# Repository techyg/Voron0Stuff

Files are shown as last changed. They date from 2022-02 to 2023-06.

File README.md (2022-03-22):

# Voron0Stuff

Welome to my Voron Stuff Repository! This is where I dump files to help share what I am working on with the Voron community. You probably found this link via my Youtube Channel (Greg's Maker Corner) or through Discord.

Check out my channel by going here:
http://www.gregsmakercorner.com

Klipper Configuration Files:

** Note: Klipper often has new releases with breaking changes. I try to keep these files updated, but please beware that they may not work with the latest version of Klipper. This is especially true of the printer.cfg files which seem to break more frequently. 

DisplayEncoder.cfg - for use with the Voron 0 display. Make sure you include this file from your printer.cfg using [include DisplayEncoder.cfg]

DisplayMenu.cfg - this specifies all the custom menu options. Make sure you include this file from your printer.cfg using [include DisplayMenu.cfg]

klipper_Expander.cfg - the config file that I use for my klipper expander. Must be included from printer.cfg file.

ldokit-voron01.cfg - my printer.cfg file for the LDO Kit v0.1.

voron01-0.5-printer.cfg - printer.cfg file for my original v0.1, which uses an AC Bed and the original v0.0 motors.

Slicer Files - Prusa Slicer

Prusa*.* - Slicer profiles I use for ASA, TPU, ABS

Slicer Files - Idea Maker

Voron 0.1-export.printer  - my voron 0 printer configuration file

V0 ABS-export.bin - My ABS Settings.

V0 PLA-export.bin - My Slicer settings.

V0 TPU-export.bin - Generic TPU settings.

V0 TPE-Inland     - Settings for Inland TPE (Shore Hardness 87A)

V0 TPU-NinjaFlex  - Settings for Ninjaflex TPU (Shore Hardness 85A)

V0 TPU-SainSmart  - Settings for Sainsmart TPU (Shore Hardness 95A)

Please note that you may need to add some GCODE sections for the slicing profiles to work. Refer to my printer configuration file.

Other files:

LGXLiteHartKPCBMountv2.stl - Hartk PCB toolhead mount for the Stealthburner with LGX Lite. You will need to m3x8's (recommend using washers) and also two heat inserts for the PCB. 

LGXLiteHartKPCBMountv2.scad - Open SCAD source code file, you can customize the PCB mount fairly easily with this and Open SCAD.

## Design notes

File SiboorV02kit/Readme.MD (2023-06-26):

Kit Updates: June 2023-

Siboor now includes led nut bar adapters in their latest kits. Please double check that all screws operate before inserting (just to be on the safe side). Use my 3d printed nut adapters and m2 hex nuts if you prefer to use printed parts similar to stock. 

Learn more about the latest Changes Update to V02 kit: https://www.youtube.com/watch?v=YN2l0KVBhCg

Original Siboor V02 Kit Review:
https://www.youtube.com/watch?v=cOtdasw3uVo&t=0s

PLEASE READ BELOW FOR SIBOOR VORON 0.2 KIT NOTES. 

This repository is for all the Siboor v2 kit items that I am either changing/remixing, or noting. The goal of this is to help other Siboor V02 builders.

**Instructions for all parts: print with .1 layer for first layer to improve stiffness. The layer height is only .2 for the bottom, otherwise the nuts won't fit.
**

Modified Parts for Siboor Extrusions (MakerBeam XL). The V02 kit does include PCB inserts that you can use. If you'd rather use a plastic part, use the remix below. 

* Siboor-M2_Nut_Adapter_Rotated_x5 - remixed nut carriers that will fit the Siboor MakerBeam XL extrusions. (height reduced and width slightly reduced). 
Remixed from Voron 0.2 STL repository.
https://github.com/VoronDesign/Voron-0/tree/Voron0.2/STLs

Note: THE HEX NO NUT DROP IS A VERY TIGHT FIT AND MAY NOT WORK IN SOME CASES (see below for alternative Square Nut mod). 

The hex nuts included with the Siboor kit are approximately 2mm-2.3mm thick. The channel that the nuts can fit in is only 2.5mm tall as opposed to other extrusion designs (Mitsumi, LDO, Maker Beam XL which have more room). Unforunately, that leaves very little room for plastic No Drop nuts. 

This isn't a problem unless you want to use No Drop nuts, which make the build MUCH easier and less frustrating, especially for first time builders. Without using no drop nuts, you will have to constantly keep track of where your hexnuts are and most likely they will fall out frequently (particularly when doing the Z axis). If you want to have a good building experience, it is highly recommended to use the no drop nuts. Using no drop nuts also helps for the panels, otherwise you will have to reposition your printer every time you want to put the panels back on.

My remix below only has a .2mm thickness where the nut sits, which means they are really easy to break. I ran into issues and in some cases I had hex nuts that were too thick and these wouldn't work. 

* Siboor-V02_HexNut_1515.stl - intended to fit the included MakerBeam XL extrusions. 
Remixed from here: https://github.com/VoronDesign/VoronUsers/tree/master/printer_mods/Zen3D/V0_1515_T-nut/MakerBeam

As an alternative, you can purchase standard DIN 562 square nuts (1.8mm) and use my square no drop nut mod. This will fit much easier and be a lot less frustration putting together. 

Alternative square nuts (DIN 562):
https://amzn.to/3TCoJL9

* Siboor-V02_SqNut-1515.stl - No Drop nut holder for square nuts that are DIN 562 (1.8mm m3 hex nuts). 

Remixed from here: https://thangs.com/designer/crankshaft/3d-model/Voron%200%20No-Drop%20Square%20Nut-31348

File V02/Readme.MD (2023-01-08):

These are pre-designed Tophat PDF Files for easy cutting on Laser cutters (I use a laser cutter that wants PDF or SVG).

The files are based off the drawings from the official Voron 0.2 repository drawings, found here.

https://github.com/VoronDesign/Voron-0/tree/Voron0.2/Drawings

There are two versions:

* 100mm (91mm sides) - this is for tophats with 100mm extrusions.
* 80mm (71mm sides) - this is for tophats with 80mm extrusions.

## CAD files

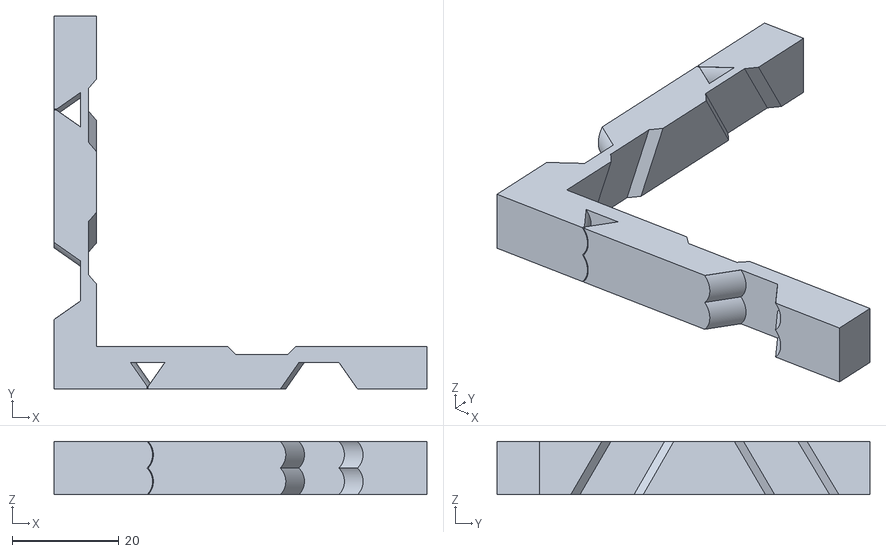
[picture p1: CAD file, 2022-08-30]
RingingTower70-10mm.stl
70.0 x 70.0 x 10.0

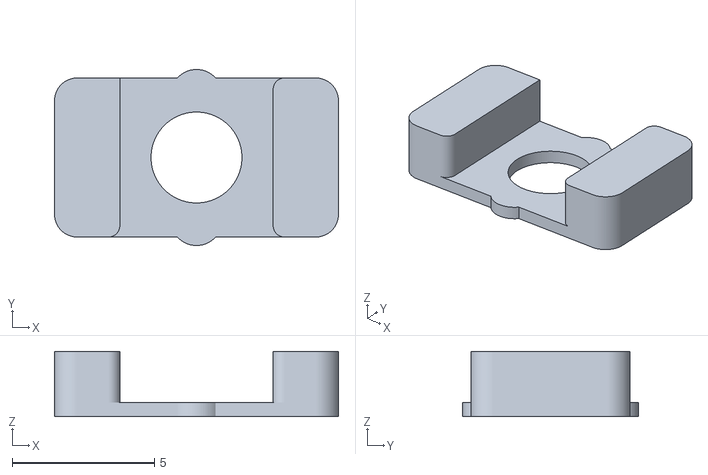
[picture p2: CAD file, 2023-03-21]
SiboorV02kit/Siboor-V02_SqNut-1515.stl
10.0 x 6.20 x 2.30

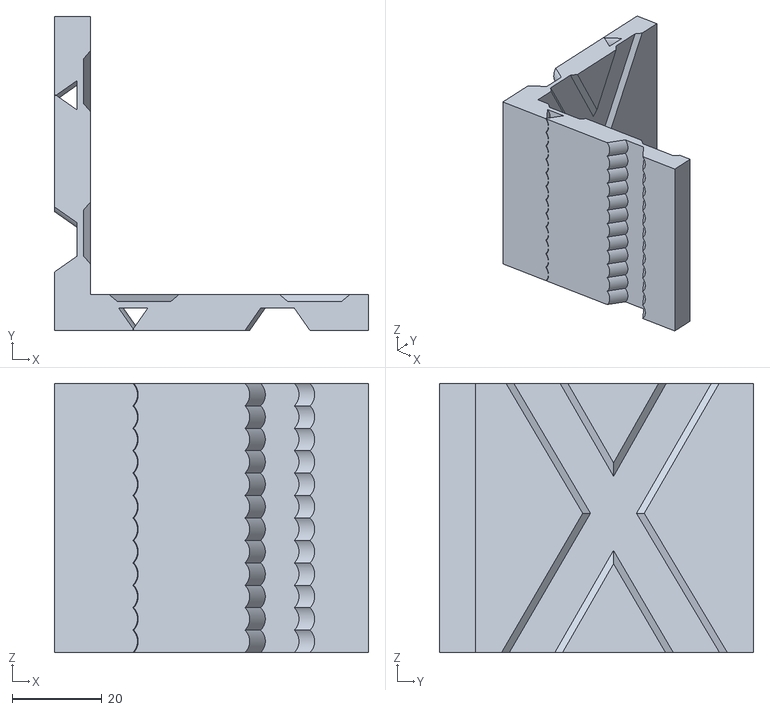
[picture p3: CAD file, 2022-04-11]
RingingTower70.stl
70.0 x 70.0 x 60.0

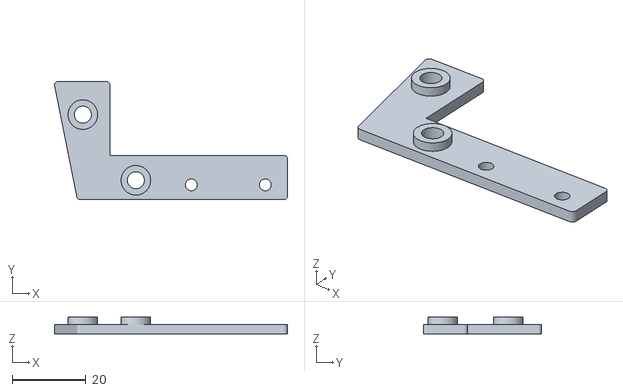
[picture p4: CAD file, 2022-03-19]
LGXLiteHartKPCBMountv2.stl
63.0 x 32.0 x 4.50

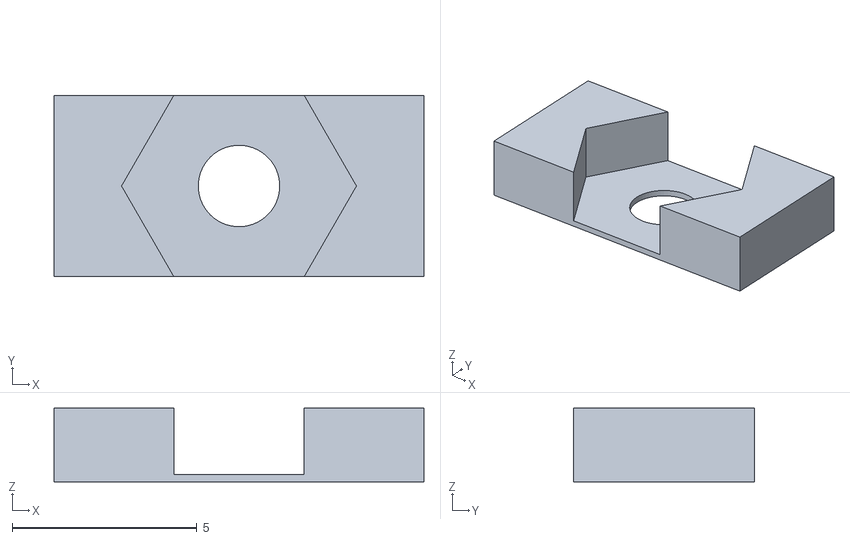
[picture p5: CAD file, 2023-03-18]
SiboorV02kit/Siboor_V02_HexNut_1515.stl
10.0 x 4.90 x 2.00

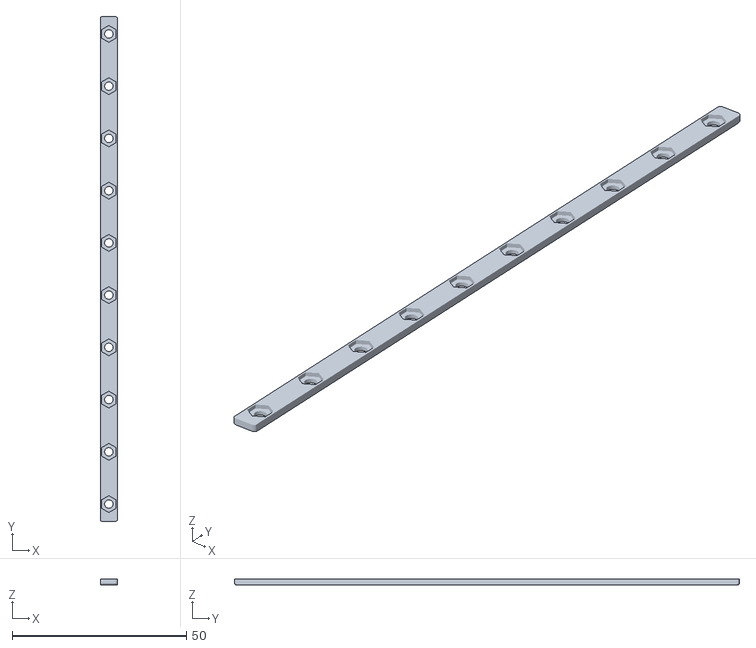
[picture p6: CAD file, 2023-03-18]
SiboorV02kit/Siboor-M2_Nut_Adapter_Rotated_x5.stl
5.00 x 145.0 x 1.60

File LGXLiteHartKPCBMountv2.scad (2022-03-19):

//fine tune x / y position for mount here.
//mount holes will stay fixed relative and shift either X or Y offset

mount_offset_x = 0;
mount_offset_y = 0;
mountshape = ([[30,0],[24,30],[37,30],[37,10],[85,10],[85,0]]);

lgx_offset_x = 0;
lgx_offset_y = 0;


//no need to modify below these lines

$fn=100;
buffer = 15;
end=45;

tophole_x=end-buffer+15;
tophole_y=4.25;

bothole_x=end-buffer-9.3333+10;
bothole_y=22;

module pcb_mount_cylinders()
{


    difference()
    {   
            union()
            {          
            translate([tophole_x,tophole_y,0])
            cylinder(h=4.5, r=8/2);
                
            translate([bothole_x,bothole_y,0])
            cylinder(h=4.5, r=8/2);   
            }
    
     }        
}

module pcb_mount_cylholes()
{
    
            //mounting holes
            translate([tophole_x,tophole_y,0])
            cylinder(h=5.1, r=4.6/2);
                
            translate([bothole_x,bothole_y,0])
            cylinder(h=5.1, r=4.6/2);      
}

difference()
{

        union()
        {
            minkowski()
            {
                linear_extrude(1.5)
                polygon(mountshape);
                cylinder(r=1);
            }

            //fine tune the movement here of cylinder mounts
            translate([mount_offset_x,mount_offset_y,0])
            {
                pcb_mount_cylinders();
            }
        }


        translate([mount_offset_x,mount_offset_y,0])
        {
            pcb_mount_cylholes();
        }

        translate([lgx_offset_x,lgx_offset_y,0])
        {
            translate([60,3,0])
            cylinder(h=2.6, r=3.2/2);
                
            translate([80,3,0])
            cylinder(h=2.6, r=3.2/2);
        }
}

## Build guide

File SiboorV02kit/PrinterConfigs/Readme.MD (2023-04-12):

My printer.cfg files for the Siboor Voron 0.2 kit.

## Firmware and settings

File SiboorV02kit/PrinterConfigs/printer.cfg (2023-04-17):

########################################
# Motherboard model
# Please modify it based on your motherboard model
# 请根据您的主板型号修改
########################################
#[include boards/FLY_GEMINI_V1.cfg]
#[include boards/FLY_GEMINI_V1.1.cfg]
[include boards/FLY_GEMINI_V3.cfg]
[include sensorless.cfg]
[include DisplayEncoder.cfg]
[include DisplayMenu.cfg]
[include gcodemacros.cfg]

[mcu]
serial: /dev/serial/by-id/usb-Klipper_stm32f405xx_JKYZ-if00

[mcu host]
serial: /tmp/klipper_host_mcu

[virtual_sdcard]
path: ~/gcode_files

[printer]
kinematics: corexy
max_velocity: 300
max_accel: 3000
max_z_velocity: 5
max_z_accel: 100


########################################
# Temp
########################################
#[temperature_sensor FLY-Gemini]
#sensor_type: temperature_host
#
#[temperature_fan mcu_fan]   #Electrical bin cooling fan
#pin: FAN1     
#kick_start_time: 0.500
#sensor_type: temperature_mcu
#control: watermark
#target_temp: 45.0
#min_temp: 0
#max_temp: 90
#max_speed: 1.0
#min_speed: 0.8

########################################
# Drives
########################################
[stepper_x]
## Refer to https://docs.vorondesign.com/build/startup/#v0
step_pin: X_STEP
dir_pin: !X_DIR
enable_pin: !X_EN
rotation_distance: 40
microsteps: 32
full_steps_per_rotation: 200                                        # Set to 400 for 0.9° degree stepper motor, 200 is for 1.8° stepper motors
endstop_pin: tmc2209_stepper_x:virtual_endstop
position_endstop: 120
position_max: 120
homing_speed: 30                                                    # Can be increased after initial setup, Max 100
homing_retract_dist: 0
homing_positive_dir: true
step_pulse_duration: 0.000004

[stepper_y]
## Refer to https://docs.vorondesign.com/build/startup/#v0
step_pin: Y_STEP
dir_pin: !Y_DIR                                                       # Check motor direction in link above. If inverted, add a ! before PC4
enable_pin: !Y_EN
rotation_distance: 40
microsteps: 32
full_steps_per_rotation: 200                                        # Set to 400 for 0.9° degree stepper motor, 200 is for 1.8° stepper motors
endstop_pin: tmc2209_stepper_y:virtual_endstop
position_endstop: 120
position_max: 120
homing_speed: 30                                                    # Can be increased after initial setup, Max 100
homing_retract_dist: 0
homing_positive_dir: true

[stepper_z]
## Refer to https://docs.vorondesign.com/build/startup/#v0
step_pin: PC15
dir_pin: !PC5                                                       # Check motor direction in link above. If inverted, remove a ! before PC4
enable_pin: !PC12
rotation_distance: 8                                                # For T8x8 integrated lead screw
microsteps: 32
endstop_pin: Z_STOP
#position_endstop: 120
position_max: 120
position_min: -1.5
homing_speed: 20
second_homing_speed: 3.0
homing_retract_dist: 3.0

[extruder]
step_pin: E_STEP
dir_pin: !E_DIR
enable_pin: !E_EN
microsteps: 16
rotation_distance: 20.7
gear_ratio: 50:10   
nozzle_diameter: 0.400
filament_diameter: 1.750
heater_pin: HEAT
sensor_pin: HEAT_TEMP
sensor_type: ATC Semitec 104GT-2
#control: pid
#pid_Kp: 22.2
#pid_Ki: 1.08
#pid_Kd: 114
min_temp: 0
max_temp: 350
min_extrude_temp: 10
step_pulse_duration: 0.000004
max_extrude_cross_section: 70


########################################
# BED
########################################
[heater_bed]
heater_pin: BED_OUT
sensor_pin: BED_TEMP
sensor_type: ATC Semitec 104GT-2
control: watermark
min_temp: 0
max_temp: 110
max_power: 1.0

########################################
# Hot end Fan - connect to FAN1 port
########################################
[heater_fan hotend_fan]
pin: FAN1
max_power: 1.0
kick_start_time: 0.5
heater: extruder
heater_temp: 50.0
#If you are experiencing back flow, you can reduce fan_speed
#fan_speed: 1.0

########################################
# Part cooling Fan 0 connect to Fan0 port (middle)
########################################
[fan]
pin: FAN0
#cycle_time: 0.50

########################################
# TMC2208 configuration./2209/2225
########################################

[tmc2209 stepper_x]
uart_pin: X_CS
interpolate: False
run_current: 1.1
sense_resistor: 0.110
stealthchop_threshold: 0                          # Set to 999999 to turn stealthchop on, and 0 to use spreadcycle
diag_pin: PA4  										# YOU NEED TO JUMP THIS DIAG PIN ON YOUR BOARD FOR SENSORLESS HOMING TO WORK 
driver_SGTHRS: 70									# 255 is most sensitive value, 0 is least sensitive


[tmc2209 stepper_y]
uart_pin: Y_CS
interpolate: False
run_current: 1.1
sense_resistor: 0.110
stealthchop_threshold: 0                          # Set to 999999 to turn stealthchop on, and 0 to use spreadcycle
diag_pin: PA5 										# YOU NEED TO JUMP THIS DIAG PIN ON YOUR BOARD FOR SENSORLESS HOMING TO WORK 
driver_SGTHRS: 70									# 255 is most sensitive value, 0 is least sensitive

[tmc2209 stepper_z]
uart_pin: Z_CS
run_current: 0.5500
interpolate: False

[tmc2209 extruder]
uart_pin: E_CS
run_current: 0.5500
interpolate: False

#*# <---------------------- SAVE_CONFIG ---------------------->
#*# DO NOT EDIT THIS BLOCK OR BELOW. The contents are auto-generated.
#*#
#*# [stepper_z]
#*# position_endstop = 119.025
#*#
#*# [extruder]
#*# control = pid
#*# pid_kp = 18.326
#*# pid_ki = 0.754
#*# pid_kd = 111.332

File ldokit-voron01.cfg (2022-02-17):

# This file contains common pin mappings for the BIGTREETECH SKR
# MINI 2.0. To use this config, the firmware should be compiled for 
# the STM32F103 with a "28KiB bootloader". Also select "enable extra 
# low-level configuration options" and configure "GPIO pins to set 
# at micro-controller startup" to "!PA14".

# The "make flash" command does not work on the SKR mini. Instead,
# after running "make", copy the generated "out/klipper.bin" file to a
# file named "firmware.bin" on an SD card and then restart the SKR
# mini with that SD card.

# See the example.cfg file for a description of available parameters.

[mcu]
##	Obtain mcu value by "ls -l /dev/serial/by-id/" 
serial: /dev/serial/by-id/usb-Klipper_stm32f103xe_32FFD6055646363311840343-if00

[stepper_x]
step_pin: PB13
dir_pin: PB12	# Remove the ! if stepper is moving the opposite direction
enable_pin: !PB14
rotation_distance: 40
microsteps: 32
full_steps_per_rotation: 200
endstop_pin: PC0 
position_endstop: 120
position_max: 120
homing_speed: 50   #Max 100
homing_retract_dist: 5
homing_positive_dir: true


[tmc2209 stepper_x]
uart_pin: PC11
tx_pin: PC10
uart_address: 0
interpolate: false
run_current: .7
sense_resistor: 0.110
stealthchop_threshold: 999999
driver_TBL: 2
driver_TOFF: 2
driver_HEND: 1
driver_HSTRT: 4
driver_PWM_LIM: 8 
driver_PWM_GRAD: 8
driver_PWM_FREQ: 1
driver_PWM_REG: 4

[stepper_y]
step_pin: PB10
dir_pin: PB2	# Remove the ! if stepper is moving the opposite direction
enable_pin: !PB11
rotation_distance: 40
microsteps: 32
full_steps_per_rotation: 200
endstop_pin: PC1
position_endstop: 121
position_max: 121
homing_speed: 50   #Max 100
homing_retract_dist: 5
homing_positive_dir: true

[tmc2209 stepper_y]
uart_pin: PC11
tx_pin: PC10
uart_address: 2
interpolate: false
run_current: .7
sense_resistor: 0.110
stealthchop_threshold: 999999
driver_TBL: 2
driver_TOFF: 2
driver_HEND: 1
driver_HSTRT: 4
driver_PWM_LIM: 8 
driver_PWM_GRAD: 8
driver_PWM_FREQ: 1
driver_PWM_REG: 4


[stepper_z]
step_pin: PB0
dir_pin: !PC5	# Remove the ! if stepper is moving the opposite direction
enable_pin: !PB1
rotation_distance: 8 #for T8x8 lead screw
#rotation_distance: 2 #for T8x2 lead screw
microsteps: 16
endstop_pin: PC2
position_endstop: -0.10
position_max: 120
position_min: -1
homing_speed: 25   #Max 100
second_homing_speed: 3.0
homing_retract_dist: 3.0


[tmc2209 stepper_z]
uart_pin: PC11
tx_pin: PC10
uart_address: 1
interpolate: True
run_current: .37
#hold_current: 0.35
sense_resistor: 0.110
#stealthchop_threshold: 500
stealthchop_threshold: 999999

[extruder]
step_pin: PB3
dir_pin: PB4	         # Remove the ! if stepper is moving the opposite direction
enable_pin: !PD2
full_steps_per_rotation: 200 # 1.8 degree motor
#rotation_distance: 22.23   # See calibrating rotation_distance on extruders doc
rotation_distance = 5.7
#gear_ratio: 50:10
microsteps: 16           #set to 8 to increase torque
nozzle_diameter: 0.400
filament_diameter: 1.750
heater_pin: PC8
sensor_type: Generic 3950
sensor_pin: PA0
#control: pid
#pid_Kp: 22.2
#pid_Ki: 1.08
#pid_Kd: 114
min_temp: 0
max_temp: 270
min_extrude_temp: 170
max_extrude_only_distance: 780.0
max_extrude_cross_section: 70
#pressure_advance: 0.38
#pressure_advance_smooth_time: 0.040

[tmc2209 extruder]
uart_pin: PC11
tx_pin: PC10
uart_address: 3
interpolate: False             #disable interpolation to increase torque and lower heat
run_current: 0.5
sense_resistor: 0.110
stealthchop_threshold: 0     #disable stealthchop to increase torque

[heater_bed]
heater_pin: PC9    		
sensor_type: NTC 100K beta 3950
sensor_pin: PC3
smooth_time: 3.0
#max_power: 0.6
#control: pid
min_temp: 0
max_temp: 120
#pid_kp: 68.453 
#pid_ki: 2.749
#pid_kd: 426.122

[verify_heater heater_bed]
check_gain_time:120


[printer]
kinematics: corexy
max_velocity: 250
max_accel: 5000                 # should be set to 4000, 7000 when tuning ringing tower
max_accel_to_decel: 5000	    # should be set to 4000, 7000 when tuning ringing tower
max_z_velocity: 10
max_z_accel: 30
square_corner_velocity: 5.0

[heater_fan hotend_fan]
pin: PC7
max_power: 1.0
kick_start_time: 0.5
heater: extruder
heater_temp: 50.0
#If you are experiencing back flow, you can reduce fan_speed
#fan_speed: 1.0

[fan]
pin: PC6						#PC9 is Bed heater PC7 is PWM controlled FAN1
kick_start_time: 0.5
#depending on your fan, you may need to increase or reduce this value
#if your fan will not start
off_below: 0.13
cycle_time: 0.010

[idle_timeout]
timeout: 1800

[homing_override]
axes: z
set_position_z: 0
gcode:
   G90
   G0 Z5 F600
   G28 X Y
   G0 X30 Y0 F3600 
   
   G28 Z
   G0 Z10 F1800
   G0 X60 Y60 Z20 F3600

###Fluidd Configs###

[virtual_sdcard]
path: ~/gcode_files

[pause_resume]

[display_status]

###Input Shaper### You need to do this manually
#[mcu rpi]
#serial: /tmp/klipper_host_mcu

#[adxl345]
#cs_pin: rpi:None

#[resonance_tester]
#accel_chip: adxl345
#probe_points:
#    60,60,20  # an example

[input_shaper]
shaper_freq_x: 38.1  # frequency for the X mark of the test model
shaper_freq_y: 47  # frequency for the Y mark of the test model
shaper_type: mzv
#damping_ratio_x: 0.1
#damping_ratio_y: 0.1


# Tool to help adjust bed leveling screws. One may define a
# [bed_screws] config section to enable a BED_SCREWS_ADJUST g-code
# command.
[bed_screws]
screw1: 60,5
screw1_name: front screw
screw2: 10,110
screw2_name: back left
screw3: 110,110
screw3_name: back right

[gcode_macro TEXTURED_BED]
gcode:
  SET_GCODE_OFFSET Z=-0.10

[gcode_macro M600]
variable_extr_temp: 0
gcode:
 PAUSE
 G91
 G1 E-.8 F2700
 G1 Z{Z}
 G90
 G1 X{X} Y{Y} F3000

[gcode_macro LEVEL_BED]
gcode:
    G28
    BED_SCREWS_ADJUST

[gcode_macro LOAD_FILAMENT]
gcode:
   M83                            ; set extruder to relative
   G1 E40 F600                    ; slower extrusion for hotend path
   G1 E10 F150                    ; prime nozzle with filament
   M82                            ; set extruder to absolute


[gcode_macro UNLOAD_FILAMENT]
gcode:
   M83                            ; set extruder to relative
   G1 E10 F600                    ; extrude a little to soften tip
   G1 E-60 F300                 ; retract filament completely
   M82                            ; set extruder to absolute

[gcode_macro PAUSE]
rename_existing: BASE_PAUSE
gcode:
    SAVE_GCODE_STATE NAME=PAUSE_state
    BASE_PAUSE
    G91
    G1 E-{E} F2100
    G1 Z{Z}
    G90
    G1 X{X} Y{Y} F6000

[gcode_macro RESUME]
rename_existing: BASE_RESUME
gcode:
    G91
    G1 E{E} F2100
    G90
    RESTORE_GCODE_STATE NAME=PAUSE_state MOVE=1
    BASE_RESUME

[gcode_macro CANCEL_PRINT]
rename_existing: BASE_CANCEL_PRINT
gcode:
    TURN_OFF_HEATERS
    CLEAR_PAUSE
    G91 
    G1 Z5 
    G90
    G92 E0
    G1 X118 Y118 E-3
    G92 E0
    M84 XYE
    SDCARD_RESET_FILE
    BASE_CANCEL_PRINT

# Convert Marlin linear advance (M900) commands to Klipper (SET_PRESSURE_ADVANCE) commands.
# For use with Marlin's linear advance calibration: https://marlinfw.org/tools/lin_advance/k-factor.html
[gcode_macro M900]
gcode:
	# Parameters
	{% set pa = params.K|float %}
	SET_PRESSURE_ADVANCE ADVANCE={pa}
    
[gcode_macro START_PRINT]
#configure the params below to tune the stage desired temperatures based on the standby temps
gcode:
    #M73 P0                       ; clear GLCD progress bar
    G21                          ; set to mm
    M107                         ; disable fans
    G90                          ; absolute positioning
    M83                          ; extruder to relative mode
    G92 E0                       ; set extruder to zero
    G28                          ; home
    G1 Z0.6 X0 Y2 F2000.0        ; move to 0,0
    M140 S{MATERIAL_BED_TEMPERATURE}                                                           ; wait for bed temp  
    M104 S{MATERIAL_PRINT_TEMPERATURE}                                                         ; set extruder
    M190 S{MATERIAL_BED_TEMPERATURE}                                                           ; wait for bed temp   
    M109 S{MATERIAL_PRINT_TEMPERATURE}                                                         ; wait for extruder temp
    G92 E0.0
    G1 Z0.2 X40 E20 F1000.0      ; intro line
    G92 E0.0
    M400                         ; clear buffer
    #M117 CARRIE Printing...      ; LCD status message
    
[gcode_macro END_PRINT]
gcode:
    M400                        ; clear buffer
    M104 S0                     ; turn off temperature
    M140 S0                     ; turn off heatbed
    M107                        ; turn off fan
    G91                         ; relative positioning
    G1 Z5                       ; move Z down 5mm
    G90                         ; absolute positioning
    G1 F1000.0                  ; set feed rate
    G1 E-3                      ; retract
    G1 X118 Y118 F3000          ; home X axis
    M221 S100                   ; Reset Filament Flowrate
    M84 XYE                      ; disable motors


#[include klipper_Expander.cfg]
[include DisplayEncoder.cfg]
[include DisplayMenu.cfg]
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

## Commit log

2021-08-03 Uploaded files
    Initial files
    [voron01-0.5-printer.cfg]
2021-12-18 Add files via upload
    Files for my voron 0 screen configuration, referenced by printer.cfg.
    [DisplayEncoder.cfg, DisplayMenu.cfg]
2021-12-18 Add files via upload
    Updated printer.cfg file and contains references to display.cfg and displayencoder.cfg.
    [voron01-0.5-printer.cfg]
2021-12-18 Add files via upload
    Klipper expander file referenced by printer.cfg.
    [klipper_Expander.cfg]
2022-03-15 Add files via upload
    Slicer settings for TPU (95A) on Voron 2.4 350mm
2022-03-19 Add files via upload
    Allows mounting the Hartk toolhead PCB (version 4, but works with others) to the LGX Lite / Stealthburner. Still a WIP at the moment.
    [LGXLiteHartKPCBMountv2.scad, LGXLiteHartKPCBMountv2.stl]
2022-07-01 My Voron Printer Profiles (Prusa Slicer)
2023-04-17 Add files via upload
    Added entry to ensure SD Card menu option is available, as it was not included in the pre-compiled image from Siboor.
    [DisplayMenu.cfg]
2023-05-26 Add files via upload
    Fixed cancel print macro issues.
2023-05-26 Add files via upload
    Fixed issue with cancel print bug.
2023-05-26 Add files via upload
    Fixed cancel print bug.
    [gcodemacros.cfg]
2023-05-26 Add files via upload
    More cleanup
    [gcodemacros.cfg]
2023-06-13 Add files via upload
    Added a reprint function
    [DisplayMenu.cfg]
2023-06-13 Add files via upload
    Added reprint function
    [DisplayMenu.cfg]
